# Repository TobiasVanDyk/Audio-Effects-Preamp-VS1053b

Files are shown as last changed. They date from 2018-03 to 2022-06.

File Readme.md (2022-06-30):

# Audio Effects Preamp with the VS1053b

Instructable at [**Audio Effects Preamp VS1053b**](https://www.instructables.com/id/Audio-Effects-Preamp-With-VS1053b/).

[**Teensy 3.6 and Teensy 4.1 replacing the ATMega328**](https://github.com/TobiasVanDyk/VS1053B-Teensy-36-and-41-Music-Effects) used in the orginal project.

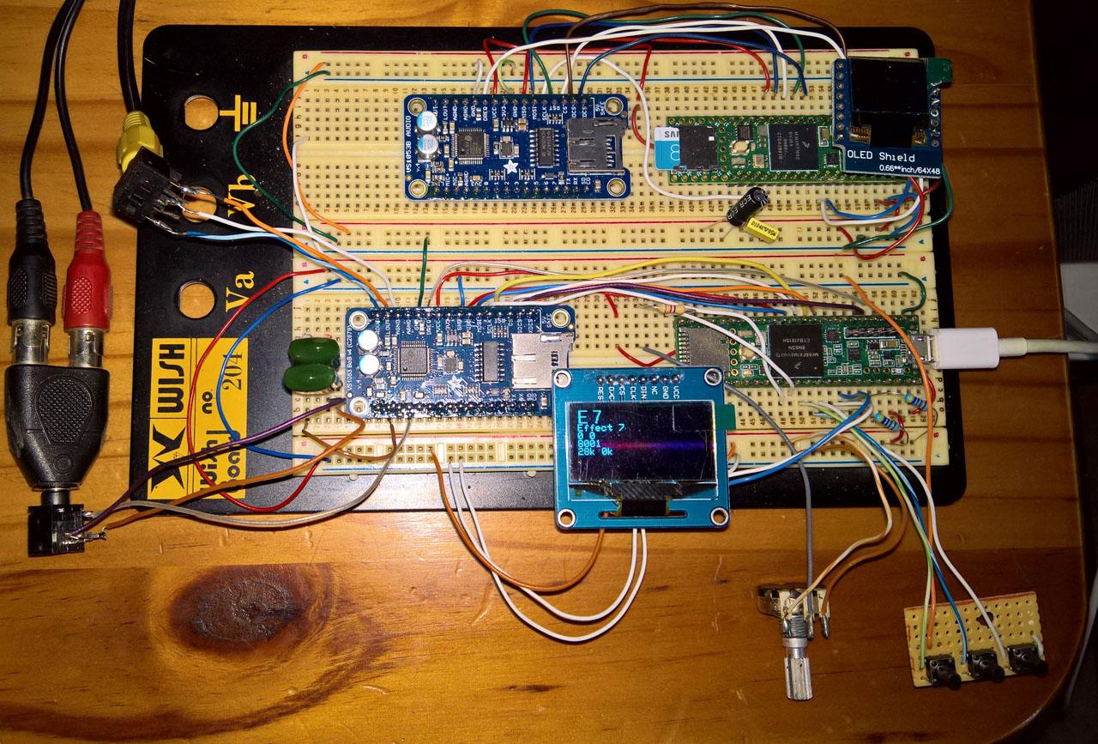
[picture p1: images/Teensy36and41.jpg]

 
### Introduction: 

This is a fully functional audio effects preamp using the VLSI VS1053b Audio DSP IC. It has a potentiometer to adjust the volume and the five effect parameters. It has nine fixed effects and one customizable effect, where each effect has five effects settings namely delay, decay-repeat, modulation speed and depth, and the mix-ratio of the processed and direct audio. It includes adjustments for bass and treble boost, bass and treble centre frequency, a selection of six input gain values, an option for saving or retrieving the current/saved parameters to/from the Arduino Eeprom, and a basic/normal/advanced/edit menu option that determines the number of functions that are cycled through. Adjustments are made using three pushbuttons, namely a function select button and two buttons to increase and decrease values for the selected function .

### Construction and Parts List

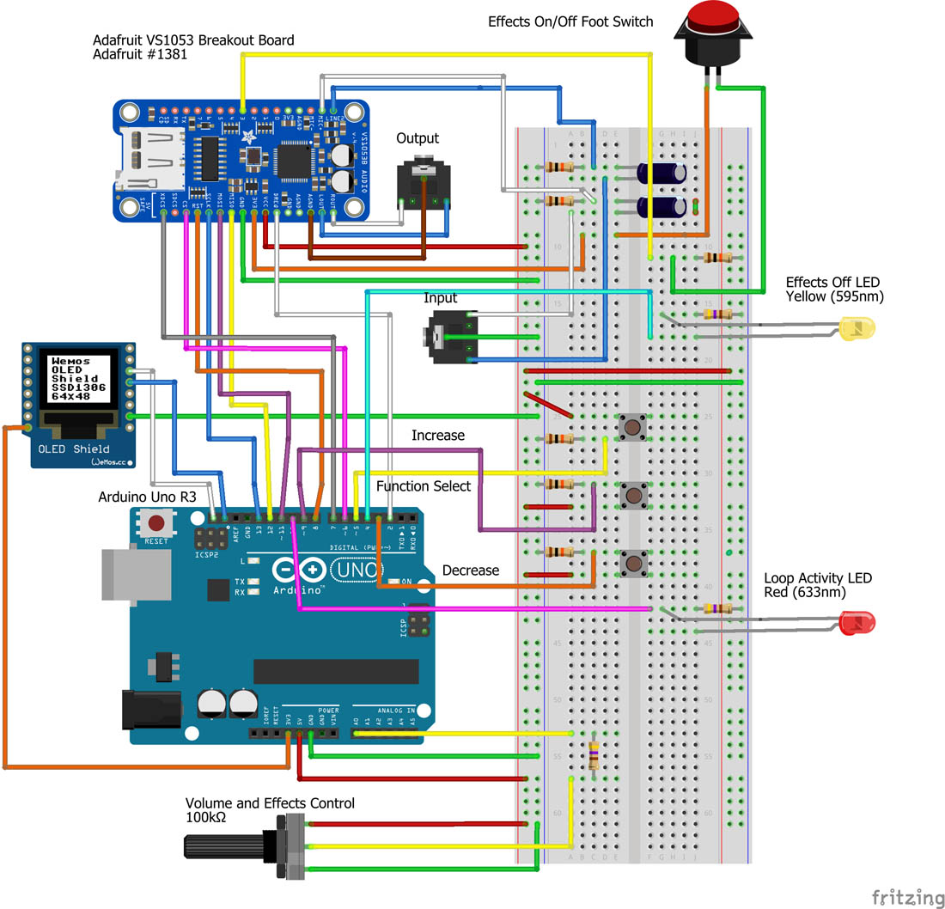
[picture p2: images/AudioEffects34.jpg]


The preamp has three pushbuttons - a function select button and two buttons to increase and decrease the selected function value. It also uses a potentiometer as a volume control, or it can be used to set values for the five effects parameters. These effects parameters are modulation speed and depth (used in chorus, phaser, and flanging effects), or delay time and repetition (used in echo and reverb effects). The fifth parameter is used to set the ratio of the direct to processed audio path. 

The function select button cycles through: (1) Effects select (0 to 9), (2) Volume select (adjusted with the potentiometer), (3) a bass boost adjustment, (4) a treble booost adjustment, (5) bass and (6) treble centre frequency selection (from 20Hz to 150 Hz in 10 Hz steps and from 1 kHz to 15 kHz in 1 kHz steps), (7) an input gain selection adjustable from 1/2x to 1x, up to 5x gain, (8) Saving or reading parameters to the ATmega328 eeprom, (9) function select cycle detail (from all 14 cycles to the 6 cycle edit mode that only cycles through the five effects paramers), and (10) to (14), adjustment of the five effect parameters using the potentiometer.

The Adafruit VS1053 Breakout board is recommended but the Sparkfun Board can also be used provided two jumper wires are soldered to pins 1 and 48 of the IC package. These will then be used as Line In2 and Line In1. 

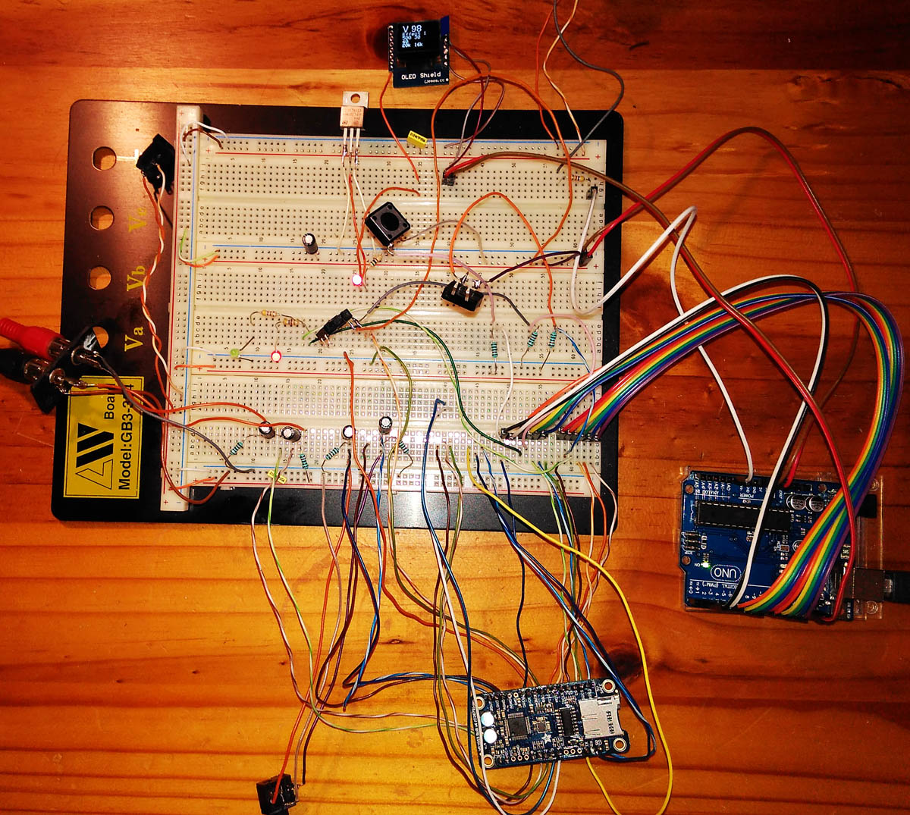
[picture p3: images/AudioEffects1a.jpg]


### Parts List:

* ATmega328 Arduino Uno R3 
* Wemos 64x48 I2C OLED Display or similar 
* Adafruit VS1053b Codec breakout board (or a Sparkfun VS1053 Breakout Board - soldering needed) 
* 3 x miniature pushbuttons 
* 100k potentiometer linear 
* 2 x Stereo audio socket to connect to an amplifier and input 
* Resistors: 5 x 10k, 3 x 470 ohm 
* Capacitors: 1uf 25v electrolytic 
* Yellow and red LED 1 x Foot Switch

### Software

The Arduino sketch attached (Effect34.ino), is based on the Adafruit VS1053 library, and the VLSI effects processing code is loaded as a plugin within the Arduino sketch.

*Further details of the VLSI effects processing can be obtained by installing their development tool - VSIDE - obtainable from their website, and then opening the folder VSIDE\templates\project\VS10X3_Audio_Effects. I used their Coff2All tool to convert the executable file into a C code type plugin which was then copied into the Arduino sketch and which loads before the loop function of the sketch starts. I changed the location of some of the variables in their example code and I therefore include the three files: effect.c and int.c and a4plugin.c. The latter is the plugin code that is loaded from the Arduino sketch.*

The software monitors three pushbuttons. The first button cycles through 9 functions and the 5 effects parameters. Function 1 offers 10 effects such as a Wet Echo, Phaser, Flanger, Chorus, Reverb and a Dry Echo as effects 0 to 6. Effects 7 and 8 are zeroed - i.e. there is no processing of the audio input - this can be changed in the Arduino code by giving values for the five effects parameters. The up and down pushbuttons are then used to select the effects function 0 to 9, or they are used to set values for the other functions such as bass boost.

This function button is also used to select the bass and treble boost vales (as 16 steps), and the centre frequency for the treble boost (1 to 15 kHz in 1 Khz steps) and the bass boost frequency (From 20 Hz to 150 Hz in 10 Hz steps. It is also used to select an input gain which can be adjusted to 0.5x, 1x, 2x, 3x, 4, or 5x gain. There is an option to save the current parameters (Volume, Bass and Treble Boost, Bass and Treble Frequency, and the five effects parameters for the customisable effect), and also to retrieve these paramers at a later stage.

Because the function select pushbutton cycles through a large number of options (15), it has an option to set a basic mode where the number of cycles are reduced to Effects Select (0 to 9), Volume Select, Bass Boost Select, Treble Boost Select, or a normal mode which adds the 5 Effects parameters to that of the basic mode, as well as its default full mode. There is also an edit mode that only cycles through the five effects parameters.

A potentiometer is used to control the volume and it is also used to set the five effects parameters for effect number 9, i.e. the effects can be adjusted by turning the potentiometer.

In addition the code running on the VS1053 caters for the installation of a footswitch connected to the VS1053 GPIO3 pin to enable or disable the currently selected audio effect. NB: This must be galvanically connected to 3.3 volt and not 5 volt (as used by the Arduino Uno). An LED is on when the effects are processed and off when it is a direct audio loopthrough. An activity LED is used to confirm important operations such as reading or writing from the Eeprom.

A slightly modified version of the Adafruit Graphics library had been used to cater for the 64x48 pixel resolution of the OLED Display - please refer to the links given at the end for Mr Mcauser. A list of the required libraries is given in the sketch code.
Credit is given to all the persons and entities mentioned for their code and libraries.

### Links

1. VLSI: http://www.vlsi.fi/en/home.html
2. Adafruit:  https://www.adafruit.com/product/1381
3. Github VS1053b:  https://github.com/adafruit/Adafruit_VS1053_Library
4. Github Graphics:  https://www.adafruit.com/product/1381
5. Oled:  https://www.adafruit.com/product/1381
6. Sparkfun:  https://www.sparkfun.com/products/12660

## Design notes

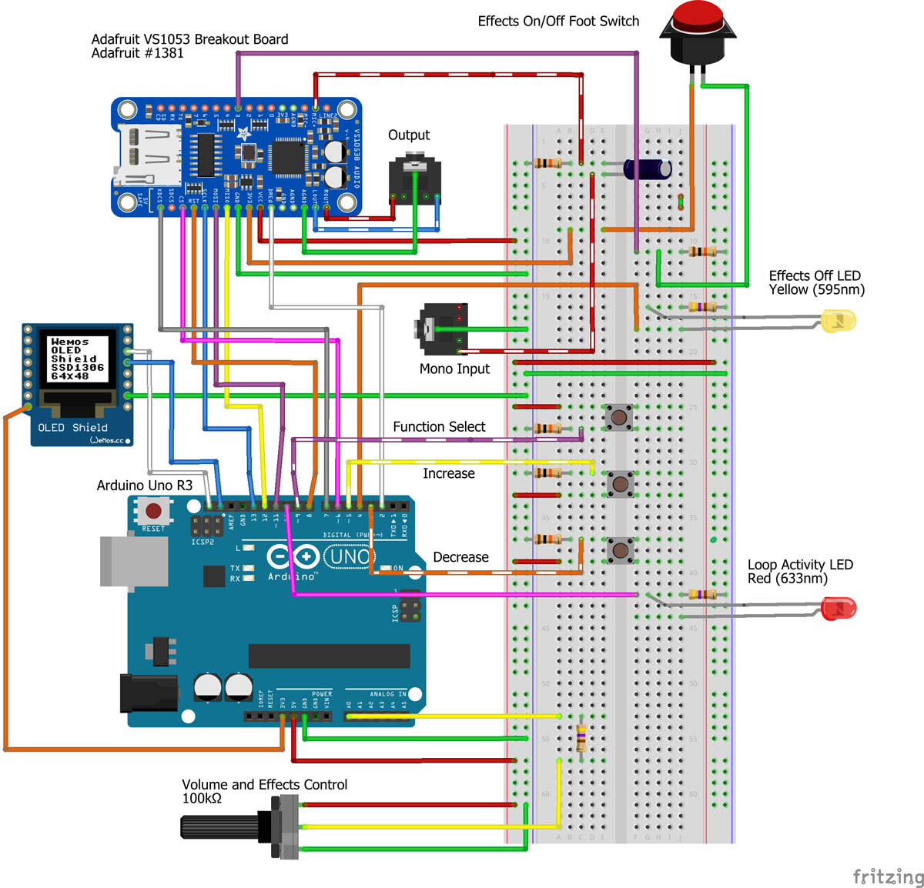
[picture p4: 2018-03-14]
images/AudioEffectsMono.jpg

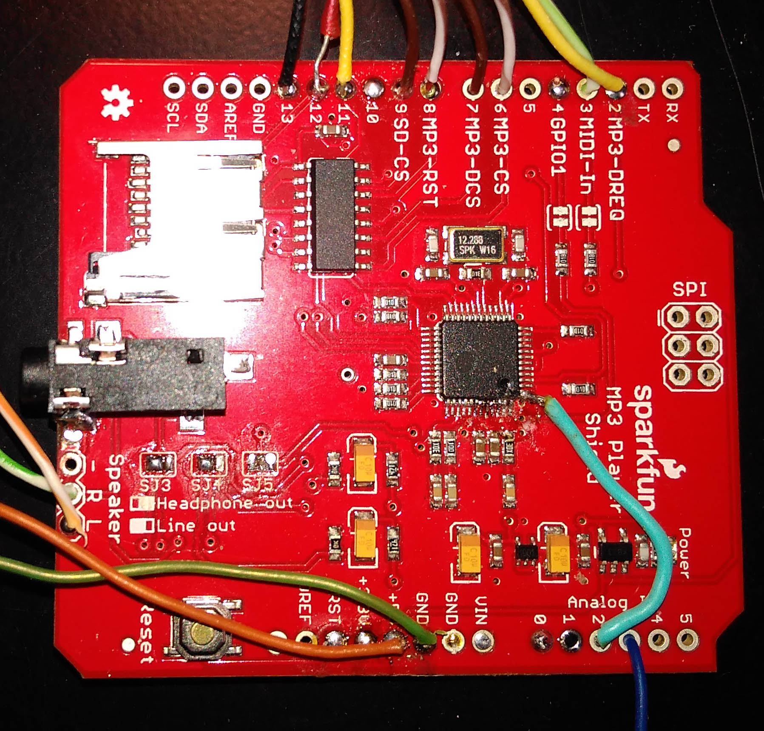
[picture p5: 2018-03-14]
images/Sparkfun2.jpg

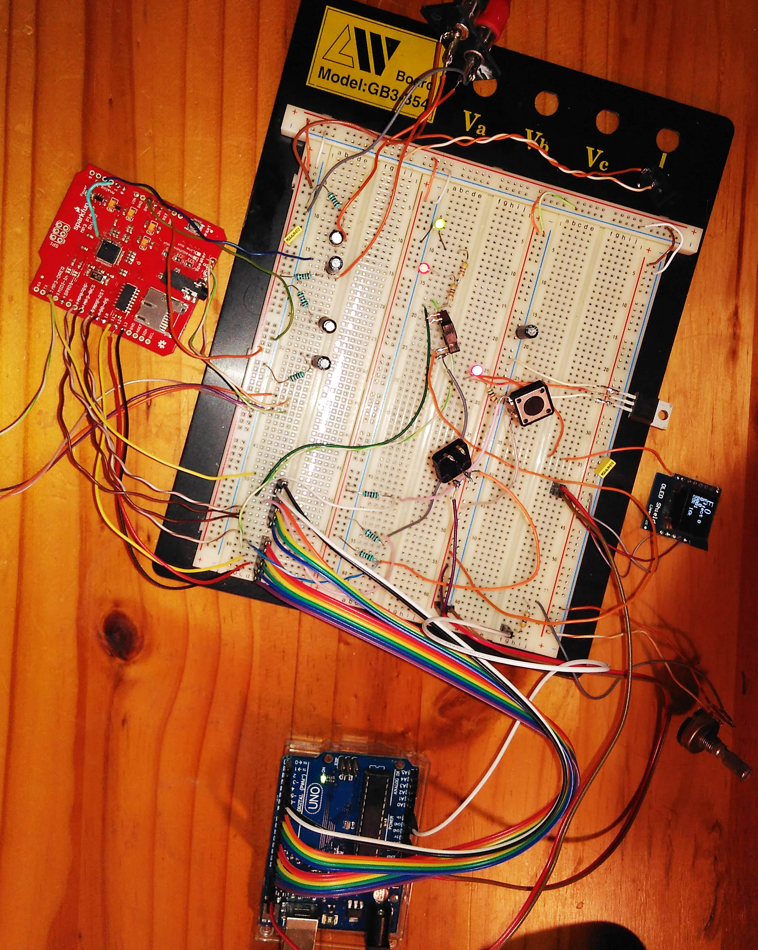
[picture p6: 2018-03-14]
images/Sparkfun1.jpg

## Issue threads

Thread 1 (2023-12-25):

Effect input is mic but no line in

SandeepJagdev, 2023-12-25:
Hello I uploaded your code to Arduino but I found problem that vs1053 accept input from mic but not line in please help

TobiasVanDyk, 2024-11-14:
Oops I missed this - VLSI coded their DSP for a mono input only unfortunately = if you look at the [**diagram here**](https://www.instructables.com/Audio-Effects-Preamp-With-VS1053b/) it is shown as a mono input. It is possible to re-write it for stereo but the maximum delay times will then be halved.

TobiasVanDyk, 2024-11-14:
Closed as based on VLSI code

Closed 2024-11-14.

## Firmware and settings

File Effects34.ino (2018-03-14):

/********************************************************************** 
  This is an example for the Adafruit VS1053 Codec Breakout

  Designed specifically to work with the Adafruit VS1053 Codec Breakout 
  ----> https://www.adafruit.com/products/1381

  Adafruit invests time and resources providing this open source code, 
  please support Adafruit and open-source hardware by purchasing 
  products from Adafruit!

  Written by Limor Fried/Ladyada for Adafruit Industries.  
  BSD license, all text above must be included in any redistribution

                 Code adapted by Tobias van Dyk
 
 ***********************************************************************/

// include SPI, MP3 and SD libraries
#include <SPI.h>
#include <Adafruit_VS1053.h>
#include <avr/pgmspace.h>
#include <Adafruit_GFX.h>
#include <Adafruit_SSD1306.h>
#include <Fonts/FreeSans9pt7b.h>
#include <EEPROM.h>

// define the pins used 13, 12, 11, 10, 9, 8, 7, 6, 5, (4), 3, 2, A0, A4, A5
// pins unused A1, A2, A3
//#define CLK 13       // SPI Clock, shared with SD card
//#define MISO 12      // Input data, from VS1053/SD card
//#define MOSI 11      // Output data, to VS1053/SD card
// Connect CLK, MISO and MOSI to hardware SPI pins. 
// See http://arduino.cc/en/Reference/SPI "Connections"

// These are the pins used for the breakout example
#define BREAKOUT_RESET  8      // VS1053 reset pin (output)
#define BREAKOUT_CS     6      // VS1053 chip select pin (output)
#define BREAKOUT_DCS    7      // VS1053 Data/command select pin (output)

// These are common pins between breakout and shield
#define CARDCS -1 // Card chip select pin not used here but needed in main lib
// DREQ should be an Int pin, see http://arduino.cc/en/Reference/attachInterrupt
#define DREQ 2    // VS1053 Data request, ideally an Interrupt pin

#define OLED_RESET 0     // GPIO0
Adafruit_SSD1306 display(OLED_RESET);
#if (SSD1306_LCDHEIGHT != 48)
#error("Height incorrect, please fix Adafruit_SSD1306.h!");
#endif

const static word plugin[907] PROGMEM = { /* Compressed plugin */
        0x0007,0x0001, /*copy 1*/
	0x8050,
	0x0006,0x036e, /*copy 878*/
	0x0030,0x0697,0x3700,0x0024,0x0000,0x0801,0xc010,0x0024,
	0x3f00,0x0024,0x2800,0x15c0,0x0006,0x2016,0x0038,0x0011,
	0x0038,0x0002,0x0000,0x2197,0xb886,0x184c,0xb88c,0x3848,
	0x3e05,0xb814,0x2912,0x1300,0x3685,0x0024,0x0007,0x9250,
	0x0000,0x0000,0xc890,0x2000,0x0002,0x0010,0x3000,0x4024,
	0x0002,0x0090,0xa100,0x0024,0x6092,0x0000,0x4010,0x0024,
	0xb882,0x2000,0x0008,0x0000,0x2915,0x7ac0,0x0038,0x0010,
	0x2912,0x1180,0x0000,0x0024,0x0018,0x0000,0x3613,0x0024,
	0xb880,0x3840,0x3e10,0x0024,0x0017,0x7000,0x2900,0x65c0,
	0x3e00,0x0024,0x0000,0x0084,0x36e3,0x0024,0x2908,0xbe80,
	0x0017,0x7005,0x0030,0x0690,0x0000,0x0241,0x3000,0x0024,
	0xc010,0x0024,0xb882,0x2000,0x0006,0xa050,0x0000,0x0000,
	0x3009,0x2000,0x0006,0xa010,0x0000,0x2000,0x3009,0x2000,
	0x0004,0x0000,0x2915,0x7ac0,0x0000,0x0010,0x0030,0x05d0,
	0x0000,0x0401,0x3000,0x0024,0xc010,0x0024,0x003f,0xfdc1,
	0x3800,0x0024,0x3000,0x0024,0xb010,0x0024,0x3800,0x0024,
	0x0030,0x02d0,0x0000,0x4040,0x2912,0x1300,0x3800,0x0024,
	0x2912,0x0ec0,0x3613,0x0024,0xf400,0x4001,0x0000,0x2000,
	0x6100,0x0024,0x0002,0x0000,0x2800,0x4509,0x0002,0x0010,
	0x0000,0x2000,0x3473,0x184c,0xf400,0x4510,0xf400,0x4512,
	0xf400,0x4513,0x2912,0x1f80,0x3493,0x0024,0x0030,0x0610,
	0x0000,0x0200,0x3000,0x4024,0xb100,0x0024,0x0002,0x0150,
	0x2800,0x42c5,0x003f,0xfbc1,0x0002,0x0110,0x0000,0x0000,
	0x3800,0x0024,0x0002,0x01d0,0x3800,0x0024,0x0030,0x0650,
	0x3000,0x0024,0xb010,0x0024,0xb882,0x2000,0x0000,0x1000,
	0x6100,0x0024,0x0002,0x0050,0x2800,0x3c01,0x003f,0xffc0,
	0x6030,0x8404,0xfe88,0x0024,0x48ba,0x0024,0x4580,0x4444,
	0x003f,0xffc5,0x6458,0x044c,0x0002,0x0210,0x2800,0x30c8,
	0xb888,0x0024,0x0038,0x0011,0x6898,0x0024,0x3801,0x104c,
	0x0002,0x0110,0x3009,0x3041,0x3009,0x33d1,0x3c30,0x8404,
	0x3c00,0xb3c3,0xfeb8,0x4491,0x48bb,0xc637,0x4058,0x03c0,
	0x001f,0x4005,0x6502,0xb087,0xfe9e,0x044c,0x48b6,0x0c8c,
	0xfe88,0x0024,0x1fff,0xfc44,0x4db6,0x0024,0xf400,0x40c3,
	0xad46,0x0024,0x3a00,0x8024,0x3200,0x4024,0x3000,0x0024,
	0xfe82,0x3004,0x48b6,0xb385,0x6500,0x1006,0x3009,0x1087,
	0xfe8e,0x13c4,0x4db6,0x0880,0xf400,0x40c3,0xad4a,0x1002,
	0xf400,0x4090,0x3900,0x1383,0x003f,0xffc0,0x3009,0x2004,
	0x6200,0x93d1,0x3009,0x13c1,0x2800,0x3b48,0x0002,0x0250,
	0x0038,0x0002,0x6890,0x0024,0x3800,0x0024,0x2800,0x2cc0,
	0x6192,0x0024,0x0000,0x0000,0x2800,0x3ac0,0x6294,0x2000,
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
	0x0007,0x0001, /*copy 1*/
	0x0800,
	0x0006,0x0006, /*copy 6*/
	0x0000,0x0000,0x1f40,0x6d60,0x3e80,0x3e80,
	0x0006, 0x8004, 0x0000, /*Rle(4)*/
	0x0007,0x0001, /*copy 1*/
	0x8023,
	0x0006,0x0002, /*copy 2*/
	0x2a00,0x4cce,
	0x000a,0x0001, /*copy 1*/
	0x0050};
#define PLUGIN_SIZE 907

const static byte Scale[256] PROGMEM = {   0,  1,  3,  5,  7,  9, 11, 13, 15, 17, 19, 21, 23, 25, 27, 31,
                                          60, 80,100,120,140,160,180,200,217,217,217,217,220,220,220,220,
					                               230,230,230,230,230,230,230,230,235,235,235,235,235,235,235,235,
                                         236,236,236,236,236,236,236,236,237,237,237,237,237,237,237,237,
                                         238,238,238,238,238,238,238,238,239,239,239,239,239,239,239,239,
                                         240,240,240,240,240,240,240,240,240,240,240,241,241,241,241,241,
                                         241,241,242,242,242,242,242,242,242,242,242,242,244,244,244,244,
                                         244,244,244,244,244,244,244,244,244,244,244,244,246,246,246,246,
                                         246,246,246,246,246,246,246,246,246,246,246,246,248,248,248,248,
                                         248,248,248,248,248,248,248,248,248,248,248,248,249,249,249,249,
                                         249,249,249,249,249,249,249,249,249,249,249,249,249,249,249,249,
                                         250,250,250,250,250,250,250,250,250,250,250,250,251,251,251,251,
                                         251,251,251,251,251,251,251,251,251,251,251,251,252,252,252,252,
                                         252,252,252,252,252,252,252,252,252,252,252,252,253,253,253,253,
                                         253,253,253,253,253,253,253,253,253,253,253,253,254,254,254,254,
                                         254,254,254,254,254,254,254,254,254,254,254,254,254,254,254,254 };

const static int GainValue[6] PROGMEM = {512,1024,2048,4096,8192,16384};

const static word EffectsParam[60] PROGMEM = {0,0,8001,28000,16000,16000,
                                              500,30,40,20000,16000,16000,
                                              0,0,0,28000,16000,16000,
                                              0,0,2000,20000,16000,16000,
                                              500,30,500,20000,16000,16000,
                                              800,50,400,20000,16000,16000,
                                              0,0,8000,28000,16000,16000,
                                              0,0,8001,28000,0,0,
                                              50,50,50,50,18000,18000,
                                              0,0,0,0,0,0};

uint16_t cp9[6] = {0, 0, 0, 0, 0, 0}; // Effects Parameters Custom

uint16_t p09[6] = {0, 0, 0, 0, 0, 0}; // Effects Parameters = EffectsParam[0-8]

const static byte Menu3[6] PROGMEM   =    { 9,10,11,12,13,14 };
const static byte Menu2[14] PROGMEM  =    { 1, 2, 3, 4, 5, 6, 7, 8, 9,10,11,12,13,14 }; 
const static byte Menu1[10] PROGMEM  =    { 1, 2, 3, 4, 9,10,11,12,13,14 }; 
const static byte Menu0[5] PROGMEM   =    { 1, 2, 3, 4, 9 };
const static byte MNumber[4] PROGMEM =    { 5, 10, 14, 6 };
const static byte MNumber9[4] PROGMEM =   { 4, 4, 8, 0 };
byte mPos = 0;
byte mNum = 14;

#define btnFunc 5          // D5 Select Function
#define btnNext 9          // D9 Up Button
#define btnPrev 3          // D3 Down Button
#define ActivityLED1 10    // D10 Show Activity
#define ActivityLED2 4     // D10 Show Activity
#define ActivityLED3 A1    // A1 or D15 Show Activity

byte Volume = 0x0101;
byte Effect = 0;
int Bass = 0;     	// 0 - 15  All used to generate 16 bit int SCI_BASS
int Treble = 0;   	// 0 - 15
int BassFreq = 6;       // 2 - 15
int TrebleFreq = 10;    // 1 - 15
byte Gain = 1;          // 0 - 5 0.5x to 4x translates to 512 to 16384
byte Menu = 2;          // Start with Advanced Menu 0 = Basic Menu 1 = Intemediate Menu 3 Edit Menu
  
//booleans to activate when btnpressed
boolean AnyBtnPress = false;
int Pot0, Pot1 = 0;     // Values 0 to 1023
int Pot0Prev = 1;
byte EffectDone = 1;
byte EepromDone = 0;

// E Effect 1 V volume 2 B bass 3 T treble 4 F bassfreq 5 F treblefreq 6 
// G gain 7 M = S/W SaveWriteEeprom 8 f Menu Basic/Mid/Full 9 E Effect9 10 to 14 
const static char Function[17] PROGMEM = " EVBTFFGSfEEEEE ";  // Function Indicator V Volume 
byte FunctionNum = 1;                                          // 1 is Effect 2 is Volume
uint16_t loopVar1, loopVar2 = 0;

const char P000[] PROGMEM = "Depth";  
const char P001[] PROGMEM = "Speed";
const char P002[] PROGMEM = "Delay";
const char P003[] PROGMEM = "Decay";
const char P004[] PROGMEM = "Mix";
const char P005[] PROGMEM = "Bass";
const char P006[] PROGMEM = "Treble";
const char P007[] PROGMEM = "Freq  Hz";
const char P008[] PROGMEM = "Freq  kHz";
const char P009[] PROGMEM = "0.5x Gain";
const char P010[] PROGMEM = "1x Gain";
const char P011[] PROGMEM = "2x Gain";
const char P012[] PROGMEM = "3x Gain";
const char P013[] PROGMEM = "4x Gain";
const char P014[] PROGMEM = "5x Gain";
const char P015[] PROGMEM = "Functions";
const char P016[] PROGMEM = "Basic";
const char P017[] PROGMEM = "Normal";
const char P018[] PROGMEM = "Full";
const char P019[] PROGMEM = "Edit";
const char P020[] PROGMEM = "Up Save";
const char P021[] PROGMEM = "Down Read";
const char P022[] PROGMEM = "Saved";
const char P023[] PROGMEM = "Read";
const char P024[] PROGMEM = "Error";

const char* const PP00[25] PROGMEM = { P000, P001, P002, P003, P004, P005, P006, P007, P008, P009, P010, P011, 
                                       P012, P013, P014, P015, P016, P017, P018, P019, P020, P021, P022, P023, P024 };

// create breakout-example object!
Adafruit_VS1053_FilePlayer musicPlayer = Adafruit_VS1053_FilePlayer(BREAKOUT_RESET, BREAKOUT_CS, BREAKOUT_DCS, DREQ, CARDCS);

////////////////////////////////////////////////////////////
//
//////////////////////////////////////////////////////////// 
void setup() {

  // by default, we'll generate the high voltage from the 3.3v line internally! (neat!)
  display.begin(SSD1306_SWITCHCAPVCC, 0x3C);  // initialize with the I2C addr 0x3C (for the 64x48)
  display.clearDisplay();
  display.display();

  pinMode (btnNext, INPUT);
  pinMode (btnPrev, INPUT);
  pinMode (btnFunc, INPUT); // FunctionNum = 0
  pinMode (ActivityLED1, OUTPUT);
  digitalWrite (ActivityLED1, LOW);
  pinMode (ActivityLED2, OUTPUT);
  digitalWrite (ActivityLED2, LOW);

  AnyBtnPress = false;

  //WriteEeprom0();            // This tested successfully with Test = 195
  //Test = EEPROM.read(0);   
  
  musicPlayer.begin();  

  LoadUserCode(); // This will start effects.c

  delay (500);
  
  musicPlayer.sciWrite(VS1053_REG_BASS, 0x0a0a);
  musicPlayer.setVolume(1,1);
  
  mNum = 14;
  ReadEffects();  
        
  DoDisplay();
}
////////////////////////////////////////////////////////////
//
////////////////////////////////////////////////////////////
void loop() 
{ 
  int m = 8192;
  byte n = 0;
  
  Pot0 = analogRead(A0); //use A0 to read the electrical signal
  delay (10);
  Pot1 = analogRead(A0); 
  Pot0 = (Pot1+Pot0)/2;

  //check if the buttons are being pressed
  chkBtn();
  if (AnyBtnPress) readBtn();
   
  ////////////////////////////////////////////////////////////////////////////////////////////////
  // depth = depth of modulation (effect to delay length) 0  - 1023
  // speed = speed of modulation range 0 .. 1023 (5.7Hz)
  // delay = pre-delay (depth adds to this delay) 0 to 8191
  // decay = amount of feedback from output to input ("repeat" control for delay effect) 0 - 32000
  // mix   = mix of dry and effect signal (0 == all dry, 32000 == all effect)
  //    10  Change Depth 
  //    11  Change Speed 
  //    12  Change Delay
  //    13  Change Decay 
  //    14  Change Mix 
  //   (15) Mix Original = Mix
  ////////////////////////////////////////////////////////////////////////////////////////////////
  if (Pot0Prev != Pot0)                             // Sequence = .V.......EEEEE 
     { Pot0Prev = Pot0; 
       if (FunctionNum==2)  ChangeVol(2);
       
       if (Menu>0)                                                                  // Skip the 5 params changes if = 0
          { if (FunctionNum>9) n = FunctionNum-10;
            if ((FunctionNum==10)||(FunctionNum==11)) cp9[n] = Pot0;                // 0-1023 
            if (FunctionNum==12) m = 8192;                                          // 0-8192
            if (FunctionNum>12)  m = 32000;                                         // 0-32000
            if (FunctionNum>11)  cp9[n] = map(Pot0, 0, 1023, 0, m);  
            if (FunctionNum==14) { cp9[5] = cp9[4]; p09[5] = cp9[4]; }              // MixOrig = Mix
            if (FunctionNum>9) { p09[n] = cp9[n]; EffectDone = 0;  Effect = 9; }
            //if (FunctionNum>9) { p09[n] = cp9[n]; EffectDone = 0; }
          } 
       }
         
  DoDisplay(); 
  delay(100); 
  ReadLoopVar();
     
  if (EffectDone==0) 
     { WriteEffects ();    
       EffectDone = 1;
     }  
 
}

////////////////////////////////////////////////////////////
// From VLSI Application Notes
////////////////////////////////////////////////////////////
void LoadUserCode(void) {
  // User application code loading tables for VS10xx
  // See http://www.vlsi.fi/en/support/software/vs10xxpatches.html

  int i = 0;
  while (i< PLUGIN_SIZE) {
    word addr, n, val;
    addr = pgm_read_word (&(plugin[i++]));
    n = pgm_read_word (&(plugin[i++]));
    if (n & 0x8000U) { /* RLE run, replicate n samples */
      n &= 0x7FFF;
      val = pgm_read_word (&(plugin[i++]));
      while (n--) {
        musicPlayer.sciWrite (addr , val);       
      }
    } 
    else {           /* Copy run, copy n samples */
      while (n--) {
        val = pgm_read_word (&(plugin[i++]));
        musicPlayer.sciWrite (addr , val);        
      }
    }
  }
  return;
}
////////////////////////////////////////////////////////////
//
////////////////////////////////////////////////////////////
void ReadLoopVar()
{ uint16_t addr1 = 0x0806;
  uint16_t addr2 = 0x0807;
musicPlayer.sciWrite(VS1053_REG_WRAMADDR, addr1);
loopVar1 = musicPlayer.sciRead(VS1053_REG_WRAM);
if (loopVar1==1) digitalWrite (ActivityLED1, HIGH);
        else digitalWrite (ActivityLED1, LOW); 
musicPlayer.sciWrite(VS1053_REG_WRAMADDR, addr2);
loopVar2 = musicPlayer.sciRead(VS1053_REG_WRAM);
if (loopVar2==1) digitalWrite (ActivityLED2, LOW);
        else digitalWrite (ActivityLED2, HIGH);
}
////////////////////////////////////////////////////////////
//
////////////////////////////////////////////////////////////
void ReadEffects()
{ uint16_t addr1 = 0x0800;
  for (int n = 0; n<6; n++)
      { musicPlayer.sciWrite(VS1053_REG_WRAMADDR, addr1);
        p09[n] = musicPlayer.sciRead(VS1053_REG_WRAM);
        addr1++; // = 0x0801 to 0x0805 = Mix Original
      }
}
////////////////////////////////////////////////////////////
//
////////////////////////////////////////////////////////////
void WriteEffects()
{ uint16_t addr1 = 0x0800;
  uint16_t pp1to8 = 0;
  uint16_t n, i = 0;
  n = 6*Effect; // 6 parameters per effect - two are the same
  for (i = 0; i<6; i++)
      { pp1to8 = pgm_read_word (&(EffectsParam[n]));
        musicPlayer.sciWrite(VS1053_REG_WRAMADDR, addr1);
        if (Effect<9) musicPlayer.sciWrite(VS1053_REG_WRAM, pp1to8);
                 else musicPlayer.sciWrite(VS1053_REG_WRAM, cp9[i]); 
        n++;
        addr1++; // = 0x0801 to 0x0805
      }
}
/////////////////////////////////////////////////////////////////////////////////////////////////
// const char P000[] PROGMEM = "Depth";  
// const char P001[] PROGMEM = "Speed";
// const char P002[] PROGMEM = "Delay";
// const char P003[] PROGMEM = "Decay";
// const char P004[] PROGMEM = "Mix";
// const char P005[] PROGMEM = "Bass";
// const char P006[] PROGMEM = "Treble";
// const char P007[] PROGMEM = "Freq  Hz";
// const char P008[] PROGMEM = "Freq  kHz";
// const char P009[] PROGMEM = "0.5x Gain";
// const char P010[] PROGMEM = "1x Gain";
// const char P011[] PROGMEM = "2x Gain";
// const char P012[] PROGMEM = "3x Gain";
// const char P013[] PROGMEM = "4x Gain";
// const char P014[] PROGMEM = "5x Gain";
// const char P015[] PROGMEM = "Functions";
// const char P016[] PROGMEM = "Basic";
// const char P017[] PROGMEM = "Middle";
// const char P018[] PROGMEM = "Full";
// const char P019[] PROGMEM = "Edit";
// const char P020[] PROGMEM = "Up Save";
// const char P021[] PROGMEM = "Down Read";
// const char P022[] PROGMEM = "Saved";
// const char P023[] PROGMEM = "Read";
// const char P024[] PROGMEM = "Error";
// E Effect 1 V volume 2 B bass 3 T treble 4 F bassfreq 5 F treblefreq 6 
// G gain 7 M = S/W SaveWriteEeprom 8 f Functions Basic/Mid/Full 9 E Effect9 10 to 14 
// const static char Function[17] PROGMEM = " EVBTFFGSfEEEEE ";  // Function Indicator V Volume 
////////////////////////////////////////////////////////////////////////////////////////////////
void DoDisplay ()
{ char Chr;
  char buffer1[10];
  int dp4 = p09[3]/1000;
  int dp5 = p09[4]/1000;

  //byte RealVol = (0xFE - Volume)/5 - 40; // Max Volume is 0 now it is 10
  //if (RealVol>100) RealVol = 0;
  byte RealVol = map(Volume, 0x00, 0xFE, 100, 0);
  /////////////////////////////////////////////////////////////
  // Large Font one line 
  /////////////////////////////////////////////////////////////
  display.setFont(&FreeSans9pt7b);
  display.setTextSize(1);
  display.setTextColor(WHITE);
  display.setCursor(0,12);
  display.clearDisplay();
  Chr = pgm_read_byte_near(&(Function[FunctionNum]));
  display.print(Chr);
  if (FunctionNum<10) display.print(" "); 

  if (FunctionNum==1)  display.print(Effect);
  if (FunctionNum==2)  display.print(RealVol);
  if (FunctionNum==3)  display.print(Bass);
  if (FunctionNum==4)  display.print(Treble);
  if (FunctionNum==5)  display.print(BassFreq*10);
  if (FunctionNum==6)  display.print(TrebleFreq);
  if (FunctionNum==7)  display.print(Gain);
  if (FunctionNum==8)  display.print("R");
  if (FunctionNum==9)  display.print(Menu);
  
  if (FunctionNum>9)  display.print("9");
  /////////////////////////////////////////////////////////////
  // Small Font four lines 
  /////////////////////////////////////////////////////////////
  display.setFont();
  display.println(); 
  
  if (FunctionNum<5)                           // 1-4 Effects Volume Bass Treble
     { display.print("Effect ");
       display.println(Effect);
       display.print(p09[0]); 
       display.print(" ");
       display.println(p09[1]); 
       display.println(p09[2]); 
       display.print(dp4); 
       display.print("k ");
       display.print(dp5); 
       display.print("k ");
     }
     
  if ((FunctionNum==5)||(FunctionNum==6))     // 5 6 Bass Treble Freq
     { display.println(); 
       strcpy_P(buffer1, (char*)pgm_read_word(&(PP00[FunctionNum]))); 
       display.println(buffer1);
       strcpy_P(buffer1, (char*)pgm_read_word(&(PP00[FunctionNum+2]))); 
       display.print(buffer1);
     }  
 
  if (FunctionNum==7)                         // 7 Gain
     { display.println();
       strcpy_P(buffer1, (char*)pgm_read_word(&(PP00[FunctionNum+2+Gain]))); 
       display.print(buffer1);
     } 
      
  if (FunctionNum==8)                         // 8 Save Read
     { display.println();
       if (EepromDone==0)
          { strcpy_P(buffer1, (char*)pgm_read_word(&(PP00[FunctionNum+12]))); 
            display.println(buffer1);
            strcpy_P(buffer1, (char*)pgm_read_word(&(PP00[FunctionNum+13]))); 
            display.print(buffer1);
          }
       if (EepromDone>0) 
          { strcpy_P(buffer1, (char*)pgm_read_word(&(PP00[FunctionNum+13+EepromDone]))); 
            display.println(buffer1); 
          }
     } 
    
  if (FunctionNum==9)                         // 9 Basic - Advanced Functions 0 1 2 3
     { display.println();
       strcpy_P(buffer1, (char*)pgm_read_word(&(PP00[FunctionNum+6]))); 
       display.println(buffer1);
       strcpy_P(buffer1, (char*)pgm_read_word(&(PP00[FunctionNum+7+Menu]))); 
       display.print(buffer1);
     } 
        
  if ((FunctionNum>9)&&(FunctionNum<15)) 
     { display.println(); 
       strcpy_P(buffer1, (char*)pgm_read_word(&(PP00[FunctionNum-10]))); 
       display.println(buffer1);
       display.print(cp9[FunctionNum-10]);
     }
     
  display.display();
      
}
///////////////////////////////////////////////////
//
///////////////////////////////////////////////////
void ChangeEffect(byte UpDwn) // Effect = 1 to 9  0 is down 1 is up
{
  if (UpDwn==0) { if (Effect > 0) Effect = Effect - 1; else Effect = 9; }  // Wrap-around  
  if (UpDwn==1) { if (Effect < 9) Effect = Effect + 1; else Effect = 0; }  
  WriteEffects(); 
  ReadEffects();     
}
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

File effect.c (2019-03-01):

/* For free support for VSIDE, please visit www.vsdsp-forum.com */
// See line 49 and 56 59 and 195 198 221 224 244 245 for changes 20/12/2017

//~~~~~~~~~~~~~~~~~~~~~~~~~~~~~~~~~~~~~~~~~~~~~~~~
// Audio effect example for VS1053/VS1063
//
// Flanger, chorus and delay with adjustable parameters
// (see "effect.h" for the parameters)
//
// press button on board to bypass effect when program is running
// There's really nothing "hidden" from you in the VS1053 audio effects template. If you look at the loop in effect.c, you 
// can see that it only calls StreamBufferReadData to get the input samples and AudioOutputSamples to push samples to the DAC. 
// There are no other calls to VS1000 ROM, except the AD interrupt handler calls auto gain functions and the startup calls 
// InitHardware and SetHardware to make sure the DACs, ADCs etc are switched on. All the audio processing (effects) is done
// in the main() function of effect.c.
//~~~~~~~~~~~~~~~~~~~~~~~~~~~~~~~~~~~~~~~~~~~~~~~~

#define USE_SIMPLE_DSP_BOARD
//#define USE_PROTOTYPING_BOARD
// (define *one* of the PCB types before including board.h)
#include "board.h"

#define USE_MIC 0 // define 1 for mic-in, 0 for line-in

#include <string.h>
#include <stdlib.h>
#include "effect.h"

void InitAudioExample(u_int16 srInput,int useMicIn,u_int16 coreClock); // (see "init.c")
// Remember to never allocate buffers from stack space. So, if you
// allocate the space inside your function, never forget "static"!
static s_int16 __y delayBuffer[DELAY_BUF_SZ]; // delay line (buffer in Y memory)

// These are at addr 0x0800, 0x0801,...0x0805
// Can be accessed from Arduino with:
// addr1 = 0x0800;
// musicPlayer.sciWrite(VS1053_REG_WRAMADDR, addr1);
struct Effect {
	u_int16 depth;
	u_int16 speed;
	u_int16 delay;
	u_int16 decay;
	u_int16 mix;
	u_int16 mixOrg;
};
struct Effect __x effect = {DEPTH, SPEED, DELAY, DECAY, MIX, MIX};

// Probably at address 0x086
s_int16 __x loopVar0 = 0;

// Probably at address 0x087
// Indicate button GPIO3 being pressed
s_int16 __x NoEffect = 0;

// Probably at address 0x088
s_int16 __x loopVar1 = 0;

// Probably at address 0x089
s_int16 __x loopVar2 = 0;

// avoid being called again (when executed as a plug-in)
//extern s_int16 (*applAddr)(s_int16 register __i0 **d, s_int16 register __a1 mode, s_int16 register __a0 n);

// __y indicates that Y RAM is used
// For more information see the VSDSP tools manual
/************************************************************************************************************
We have two large ring buffers in VS1053. One of them is the stream buffer, the other the audio buffer. 
The stream buffer is used for unprocessed data, be it WAV, MP3, AAC, or something else. The audio buffer is 
used for decoded and processed, 16-bit PCM stereo audio samples that are going to the DAC. For details, see V
S1053b Datasheet Chapter 9.2, Data Flow of VS1053b.

Reading the status of the stream buffer, which lies at address y:0x1a7d, hence in BufferFillWords() there is a write of value 0x5a7d to SCI_WRAMADDR.

The fill status of the audio buffer. The address for that is y:0x1a80. The pointer works similarly as the stream buffer pointer, except that the VS1053 audio buffer size is 4 KiWords (or, 2 stereo kilosamples). You can get the audio buffer status by modifying (or duplicating) the following:
1) BufferFillWords(): replace the 0x5a7d write to SCI_WRAMADDR by 0x5a80.
2) BufferFreeWords(): replace 1023 with 4095.
3) BufferFreeWords(), replace 1024 with 4096.
http://www.vsdsp-forum.com/phpbb/viewtopic.php?t=1451
http://www.vsdsp-forum.com/phpbb/viewtopic.php?t=1463
*************************************************************************************************************/
main(void) {

	s_int16 auxBuffer[2*BLOCKSIZE];     // auxiliary audio buffer
	s_int16 __y lineInBuf[2*BLOCKSIZE]; // line-in audio buffer
	s_int16 __y *bufptr = delayBuffer;
	s_int16 __y *flgptr = delayBuffer;
	s_int16 phase = 0;                  // this is the (accumulator) phase for the LFO
	s_int16 flangerSample = 0;
	u_int16 flangerPhase = 0;
	// parameters for the currently selected effect:
		
	// need to enable interrupts when executed as a plug-in
	Enable();
	// avoid being called again (when executed as a plug-in)	
	applAddr = NULL;
	
	effect.delay += (effect.depth/2)+1;       // depth/2 added to delay
	// initialize delay line with silence
	memsetY(delayBuffer, 0, DELAY_BUF_SZ);    // delayBuffer all = 0
	// disable interrupts during initialization
	Disable();
	// basic initialization phase in int.c
	InitAudioExample(MY_SAMPLERATE,USE_MIC,CORE_CLOCK_3X); // Check if can do CORE_CLOCK_4X 3.5X 4.5X 5X
	// adjust output samplerate
	// VS1053 has 18-bit stereo DAC. DAC samplerate can be adjusted by ROM function:
	// SetHardware(2, 48000U); Stereo, 48 kHz
	// Parameters for the function are number of output channels (1 or 2) and output sample
	// rate in Hz. Fine tuning for the DAC sample rate can be done with a 32-bit number.
	// The lower 16 bits are written to the register FREQCTLL and higher 4 bits to the register FREQCTLH.
	SetHardware(2/*stereo output*/,MY_SAMPLERATE/*DA sample rate*/);
	//
	USEX(INT_ENABLE)|=(1<<INT_EN_MODU)/*AD*/|(1<<INT_EN_DAC);
	// initialize audio_buffer read and write pointers
        //extern s_int16 __y audio buffer[]; 
        //volatile extern s_int16 __y * audio_wr_pointer;
        //volatile extern s_int16 __y * audio_rd_pointer;
        // To stop playing, just set the audio_rd_pointer to audio_wr_pointer so the audio buffer seems empty.
	audio_rd_pointer = audio_buffer;               // ROM defined output buffer
	audio_wr_pointer = audio_buffer + 2*BLOCKSIZE; // Two blocksize samples ahead

	// clear audio buffer (avoid unwanted noise in the beginning)
	memsetY(audio_buffer,0,AUDIO_BUFFER_SZ);
	
	// set up GPIO in board.h
        // LED_1 (1 << 4)  Led 1 is at GPIO4
        // CONFIGURE_LED_1 {GPIO_CONFIGURE_AS_OUTPUT(LED_1);} 
        // SET_LED_1_ON GPIO_SET_HIGH(LED_1)
        // SET_LED_1_OFF GPIO_SET_LOW(LED_1)
	CONFIGURE_LED_1; 
        // BUTTON_1 (1 << 3) /* Button 1 is at GPIO3 */
        // BUTTON_1_PRESSED GPIO_IS_HIGH(BUTTON_1)
        // CONFIGURE_BUTTON_1 {GPIO_CONFIGURE_AS_INPUT(BUTTON_1);}
	CONFIGURE_BUTTON_1;
	
	// set almost max volume
	USEX(SCI_VOL) = 0x0101;
	
	//USEX(SCI_BASS) = 0xfa7a; // a=> 10khz a => 100 hz f = full +15db 7 => +10db
	//USEX(SCI_BASS) = 0x0f0f; // off

	// enable interrupts
	Enable();	
//
//~~~~~~~~~~~~~~~~~~~~~~~~~~~~~~~~~~~~~~~~~~~~~~~~
// Main loop
//~~~~~~~~~~~~~~~~~~~~~~~~~~~~~~~~~~~~~~~~~~~~~~~~
//
	while (1) {
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
